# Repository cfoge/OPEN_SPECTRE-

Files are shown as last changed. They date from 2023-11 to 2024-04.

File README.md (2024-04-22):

# OPEN_SPECTRE
## An open-source FPGA-based EMS SPECTRE video synth.
*A project aimed at recreating the EMS SPECTRE VIDEO SYNTHESIZER in HDL*


Open to donations and contributors with FPGA experience. 😀 

###  ✨The EMS SPECTRE Colour Video ✨
>Synthesizer is a unique and revolutionary new product: an instrument capable of producing exciting graphic images on an ordinary television screen. The complete SPECTRE package consists of the synthesizer itself, plus a Sony Trinitron colour monitor, and a Sony black-and-white TV camera. The synthesizer is compact (38"x23.5"x7"), portable (about 35 pounds/15.9KG), and unequalled in its simplicity and versatility.

EMS SPECTRE

### Design Info
#### 🎉Aim 🎉
The aim of this project is to preserve this rare and unique video synth by recreating it in an FPGA, but also to use it as a building block to make a Spectre that is both true to the original and also a modern tool for creativity.
For more info in this process take a look at: 
[Cloning Hardware Ethos](top%20level%20design/Cloning%20a%20process%20not%20a%20device.md)

#### 😎 Tooling 😎
[Parse VHDL](https://github.com/cfoge/VHLD_parse) *Tool set built for this project

#### 🍒Documentation🍒
[Auto Generated Documentation](https://cfoge.github.io/OPEN_SPECTRE-/) **System CURENTLY BROKEN**

#### 🥨Top Level Diagram🥨
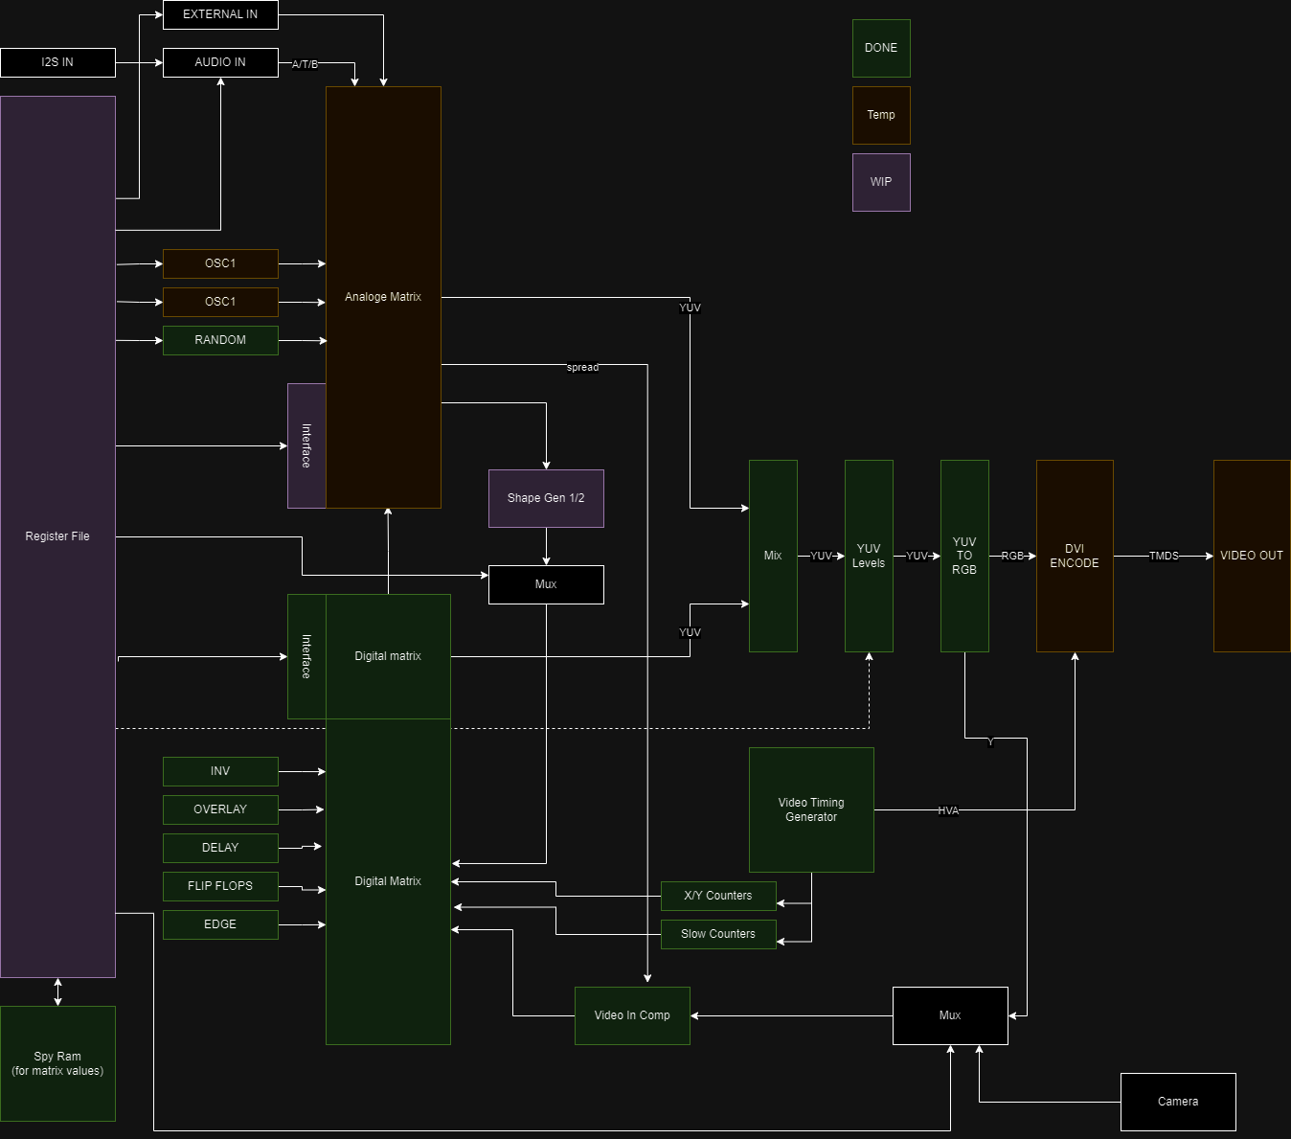
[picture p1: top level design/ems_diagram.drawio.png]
EMS Diagram

Modules

#### 🍨List of Modules and Details Phase 1🍨(WIP)

##### TEST BUILD 1 NOTES:
Simplified elements simulated, need to build a reg file to drive the muxes, there is too much logic for a vio32.
Use microblaze or Zynq to drive a reg file that drives the 20 muxes for Luma 1, Luma2 chroma 1 and chroma 2 (4bit select lines on the Mux)

List of Modules and their current state: (out of date) [here!](modules.md)

### Devlog:


If you want to watch the videos I have been making along the way, you can do that [here!](Devlog.md), or on Youtube, [here!](https://www.youtube.com/watch?v=KFnwisze7SQ&list=PLvfa5uBvhecMLK6bUgnpbkl8QMMuvigXx&pp=gAQBiAQB)

### 🍣Want to Contribute?🍣
Amazing! If you have FPGA and or Verilog/VHDL skills we would love to have you involved. But, first, there are a few things you should know. 
#### What to do first
- Look through the resources folder to get an idea of what the EMS SPECTRE is and how it works
- Look at the top-level diagram and the list of modules
#### Project Details For Contributors
- RTL in VHDL or Verilog (VHDL preferred, no system Verilog 😎 sorry) 
- One module per file with a separate testbench (Verilog or VHDL test benches only, *not everything has one yet, but it should)
- Test benches should print out a message at the end confirming if they are successful or not
- No HSL or auto-generated code, no busses or interfaces for now (will be busses later)
- Use any software you like, but a Vivado project will be supplied
- Follow the template for file headers and comments 📑
- Follow the folder structure for the project 📂
- All code must be open source or MIT license 👍

#### If after all that you still want to be involved you can do one of three things:
- Email us at *OPEN.SPECTRE.PROJECT@gmail.com* and see what modules we need to make at the moment
- Branch the repo, make a module, and submit a pull request 
- If you are not any good at git/GitHub, if you write any modules you can email them to us and we will integrate them into the project

### 🐙License🐙
Creative Commons CC BY-NC

### Contributors
-Remi Freer
-Jacob Stoker
-Robert D Jordan

### Donations
We are very thankful to have received donations from the following people:
Chris Korvin,
Jay Hotchin,
Milton Grimshaw, and more amazing anonymous people. 

[//]: # (These are reference links used in the body of this note and get stripped out when the markdown processor does its job. There is no need to format nicely because it shouldn't be seen. Thanks SO - http://stackoverflow.com/questions/4823468/store-comments-in-markdown-syntax)

   [dill]: <https://github.com/joemccann/dillinger>
   [git-repo-url]: <https://github.com/joemccann/dillinger.git>
   [john gruber]: <http://daringfireball.net>
   [df1]: <http://daringfireball.net/projects/markdown/>
   [markdown-it]: <https://github.com/markdown-it/markdown-it>
   [Ace Editor]: <http://ace.ajax.org>
   [node.js]: <http://nodejs.org>
   [Twitter Bootstrap]: <http://twitter.github.com/bootstrap/>
   [jQuery]: <http://jquery.com>
   [@tjholowaychuk]: <http://twitter.com/tjholowaychuk>
   [express]: <http://expressjs.com>
   [AngularJS]: <http://angularjs.org>
   [Gulp]: <http://gulpjs.com>

   [PlDb]: <https://github.com/joemccann/dillinger/tree/master/plugins/dropbox/README.md>
   [PlGh]: <https://github.com/joemccann/dillinger/tree/master/plugins/github/README.md>
   [PlGd]: <https://github.com/joemccann/dillinger/tree/master/plugins/googledrive/README.md>
   [PlOd]: <https://github.com/joemccann/dillinger/tree/master/plugins/onedrive/README.md>
   [PlMe]: <https://github.com/joemccann/dillinger/tree/master/plugins/medium/README.md>
   [PlGa]: <https://github.com/RahulHP/dillinger/blob/master/plugins/googleanalytics/README.md>

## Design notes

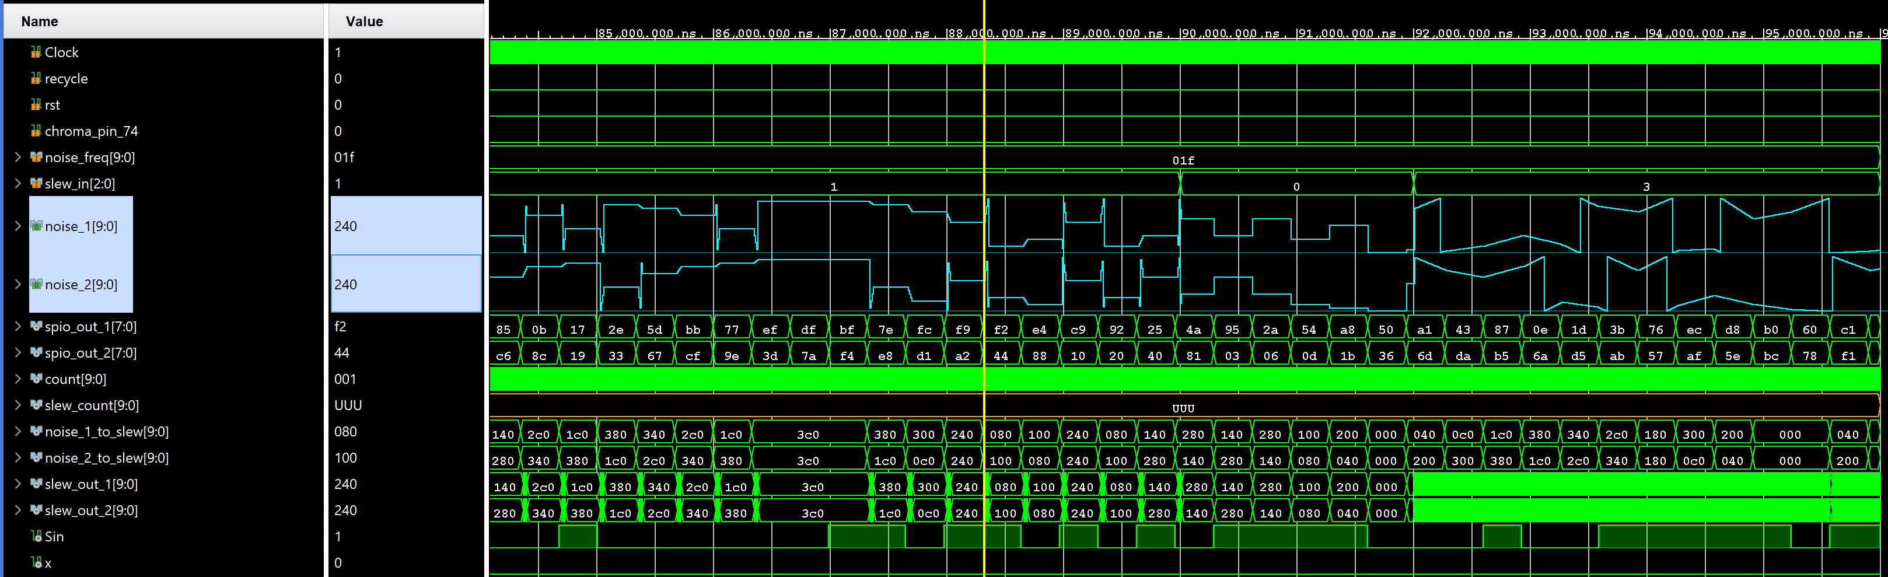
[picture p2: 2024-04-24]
fpga/src/analog_side/random_voltage/docs/random module scope.PNG

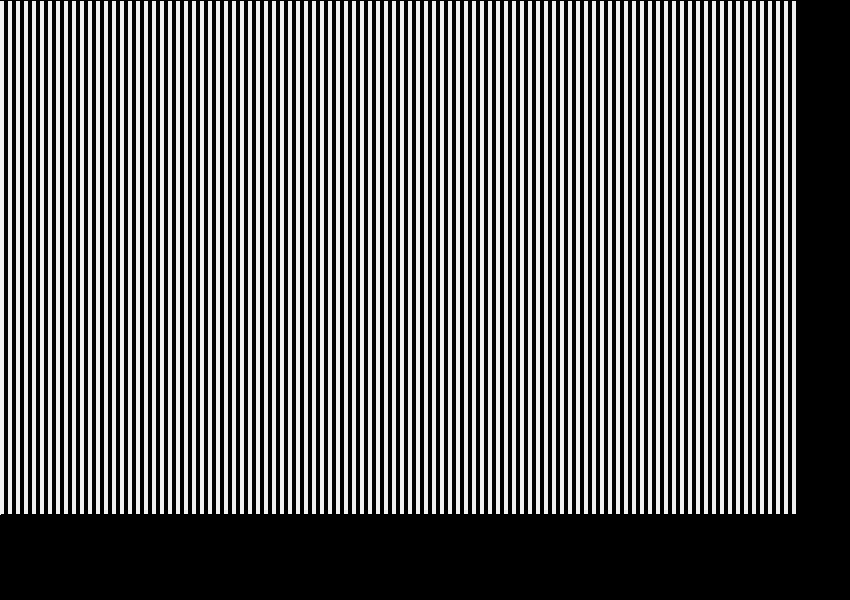
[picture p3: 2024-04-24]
fpga/tools/sim_images/x_cnt_2.png

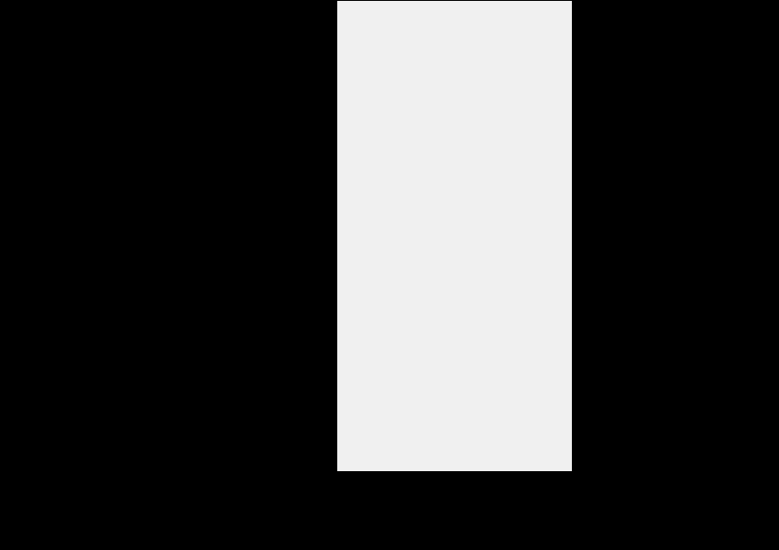
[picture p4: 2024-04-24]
fpga/tools/sim_images/x_cnt_8 blanking on.png

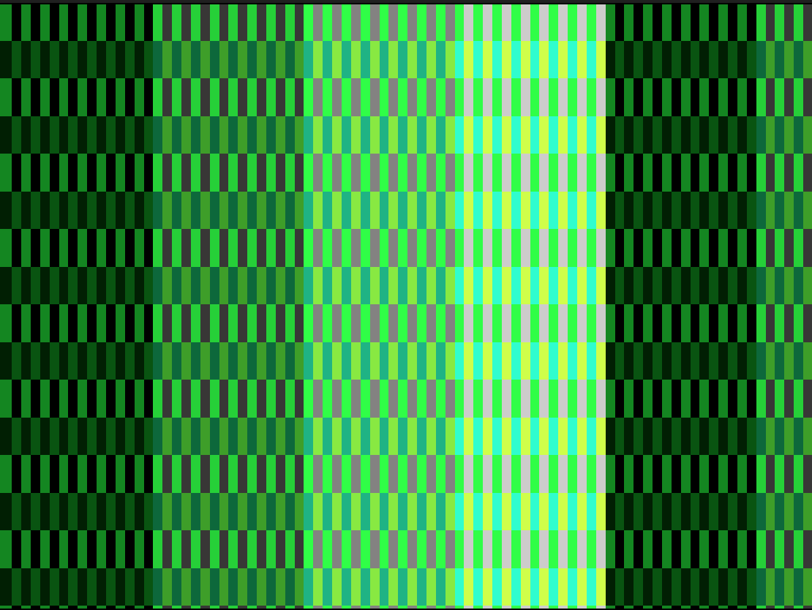
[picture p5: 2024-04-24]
fpga/tools/sim_images/play2.png

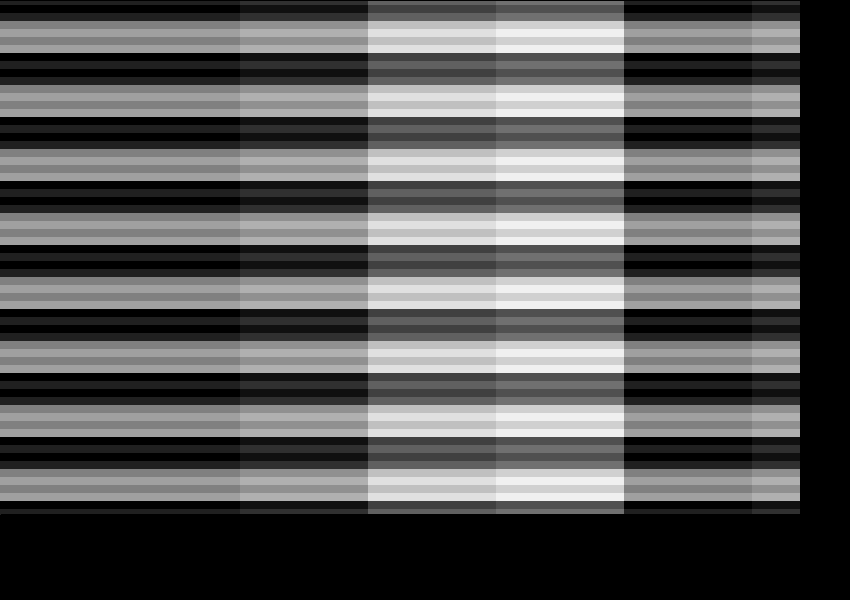
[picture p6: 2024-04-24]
fpga/tools/sim_images/x&y_cnt_combo.png

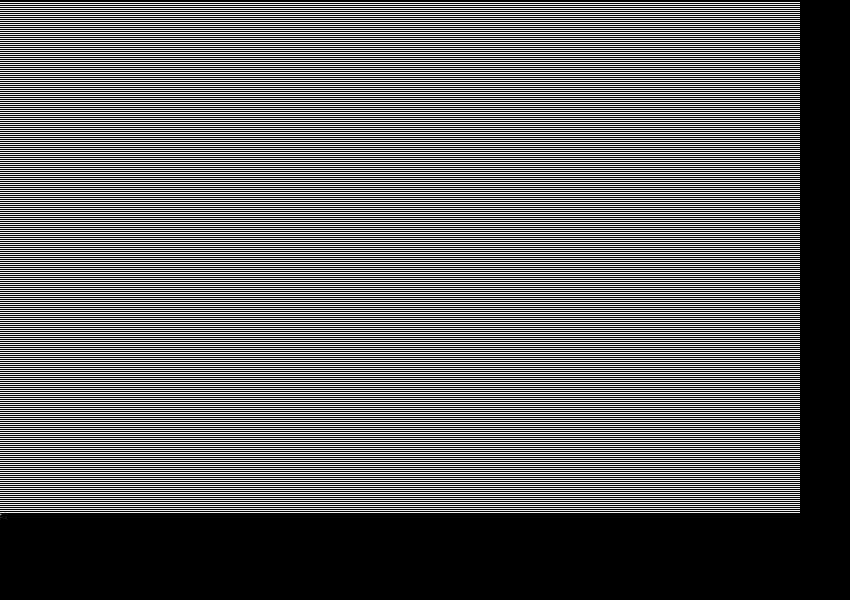
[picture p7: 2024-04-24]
fpga/tools/sim_images/y_cnt_0.png

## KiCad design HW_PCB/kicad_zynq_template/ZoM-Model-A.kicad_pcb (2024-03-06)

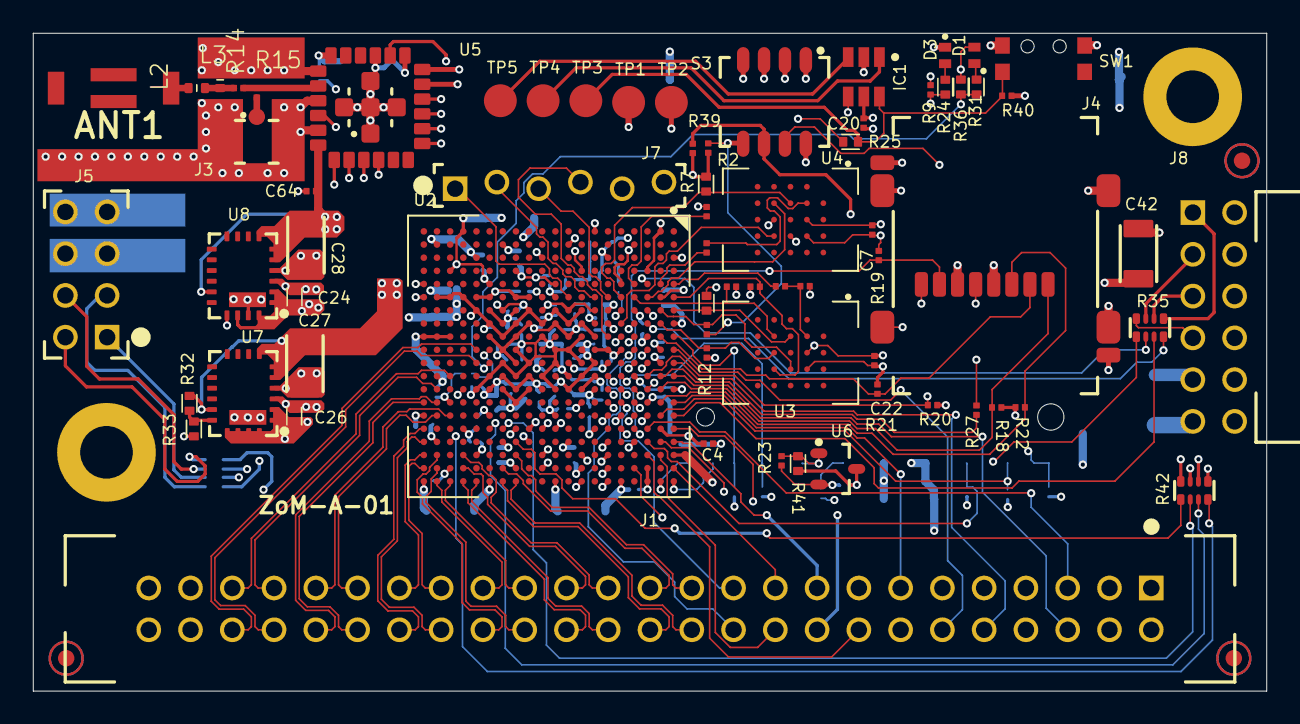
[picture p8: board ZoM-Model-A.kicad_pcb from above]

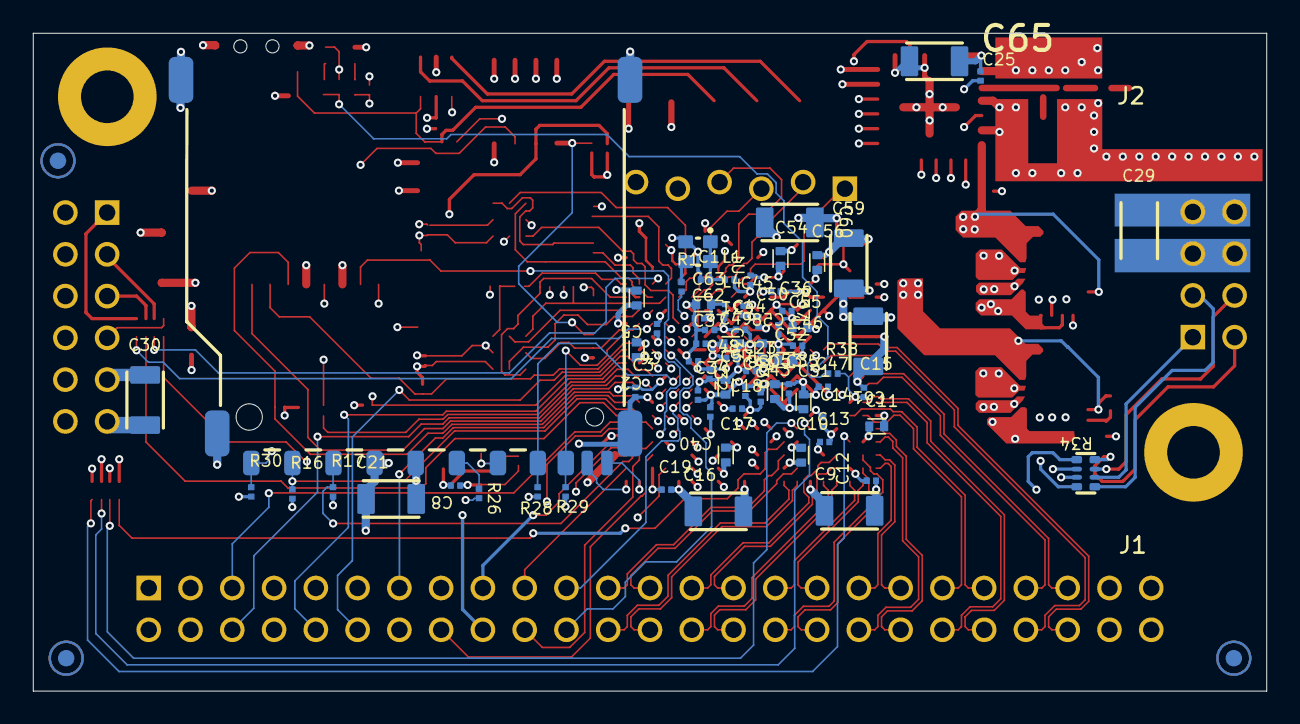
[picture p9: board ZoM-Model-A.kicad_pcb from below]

Board: 6 copper layers, 75.0 x 40.0 mm, 145 parts (72 on the bottom side), 140 nets.

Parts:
ANT1: Antena 2450AT43B100
C1, C8, C23, C34, C35, C36, C37, C41, C43, C44, C45, C46, C47, C48, C50, C64, C65: 470nF; CAPC0603X33N
C2, C5, C10, C11, C17, C24, C26, C63: 4.7µF; _AD_adlib_lib_pcb_TE-IPC7351_CAPC1005X60N.PcbLib_CAPC1005X6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
C3, C4, C6, C7, C12, C13, C14, C15, C18, C19, C20, C22, C31, C32, C33, C38, C39, C40, C62: 470nF; _AD_adlib_lib_pcb_TE-IPC7351_CAPC0603X33N.PcbLib_CAPC0603X3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
C9, C16, C21, C25, C27, C28, C29, C30, C42: 47µF; _AD_adlib_lib_pcb_TE-IPC7351_CAPC3216X180N.PcbLib_CAPC3216X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
C49, C51, C52, C53, C54, C55, C56: 4.7µF; _svn_cad_altium_pcb_contract_tt_tt-svn_ADLIB_dbww_.._lib_pc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
C57, C58: 4.7µF; CAPC1005X60N
C59, C60, C61: 100µF; CAPC3216X180N
D1: LED Red SML-P11UTT86; _AD_adlib_lib_pcb_TE-IPC7351_LEDC1006X25N_RED.PcbLib_LEDC10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
D3: LED Green SML-P11MTT86; _AD_adlib_lib_pcb_TE-IPC7351_LEDC1006X25N_GREEN.PcbLib_LEDC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
H1, H4: Mount.Hole 3.2mm; MHole3_2mm
IC1: Atmel AVR ATtiny10; _tfx_altium_lib_common_pcb_IC_IPC_SOT23-6.PcbLib_SOT23-6
J1: WANNE2,54-50 GERADE; _AD_adlib_lib_pcb_TE_WANNE2,54-50 GERADE.PcbLib_WANNE2,54-5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
J2: MMC SD Socket; _AD_adlib_lib_pcb_TE_104C-TAA0-R.PcbLib_104C-TAA0-R
J3: U.FL-R-SMT-1; _AD_adlib_lib_pcb_TE_U.FL-R-SMT-1.PcbLib_U.FL-R-SMT-1
J4: SCHD3A0100; _AD_adlib_lib_pcb_TE_SCHD3A0100.PcbLib_SCHD3A0100
J5: STIFTLEISTE2.54 OG 2R-8; STIFTLEISTE2_54 OG 2R-8
J7: Stiftleiste versetzt 1-reihig, 6pol.; _AD_adlib_lib_pcb_TE_STIFTLEISTE2_54 OG 1R-6V.PcbLib_STIFTL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
J8: PMod 2x6 Socket 90°; _AD_adlib_lib_pcb_TE_PMod2x6.PcbLib_PMod2x6
L1: BKP0603HS121-T; INDC0603X33N
L2, L3: IND-Ferrite; RESC1005X40R
L4: BKP0603HS121-T; _AD_adlib_lib_pcb_TE-IPC7351_INDC0603X33N.PcbLib_INDC0603X3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
PM1, PM2, PM3, PM4, PM5, PM6: FIDU-DOT - small
R1, R4, R8: 33R; RESC0603X26N
R2, R9, R10: 10K; RESC0603X26N
R3, R7, R24, R31: 470R; RESC1005X40N
R5, R6, R11, R12, R13, R16, R17, R18, R19, R20, R21, R22, R28, R29, R30, R39, R40: 10K; _AD_adlib_lib_pcb_TE-IPC7351_RESC0603X26N.PcbLib_RESC0603X2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
R14, R15: 0; RESC0603X26N
R23, R37: 4K7; _AD_adlib_lib_pcb_TE-IPC7351_RESC0603X26N.PcbLib_RESC0603X2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
R25: 470R; _AD_adlib_lib_pcb_TE-IPC7351_RESC1005X40N.PcbLib_RESC1005X4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
R26, R27: 33R; _AD_adlib_lib_pcb_TE-IPC7351_RESC0603X26N.PcbLib_RESC0603X2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
R32: 200K; _AD_adlib_lib_pcb_TE-IPC7351_RESC1005X40N.PcbLib_RESC1005X4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
R33: 301K; _AD_adlib_lib_pcb_TE-IPC7351_RESC1005X40N.PcbLib_RESC1005X4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
R34, R35, R42: 33R; _AD_adlib_lib_pcb_TE-IPC7351_RESCAX50P100X200X55-8N.PcbLib_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
R36: 680R; RESC1005X40N
R38: 4K7; RESC0603X26N
R41: 0R; _AD_adlib_lib_pcb_TE-IPC7351_RESC1005X40N.PcbLib_RESC1005X4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
S3: CHS-04TA; _AD_adlib_lib_pcb_TE-IPC7351_CHS-04TA.PcbLib_CHS-04TA
SW1: 4pin button; _tfx_altium_lib_common_pcb_BUT-SW_KMS221G_LFS.PcbLib_KMS221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
TP1, TP2, TP3, TP4, TP5: TP; _tfx_altium_lib_common_PCB_TP_TP-SMD-2mm.PcbLib_TP-SMD-2mm
U1: SiT8008AI-73-XXS-33.333333E; 2016
U2: XA7Z020-1CLG400I; _AD_adlib_lib_pcb_TE-IPC7351_BGA400C80P20X20_1700X1700X160N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
U3, U4: W25Q256FVBIG; _AD_adlib_lib_pcb_TE-IPC7351_BGA24C100P5X5_800X600X120N.Pcb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
U5: TiWi-uB2
U6: ATSHA204A-STUCZ-T; _AD_adlib_lib_pcb_TE-IPC7351_SOT95P237X112-3N.PcbLib_SOT95P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
U7, U8: EN5311QI; _AD_adlib_lib_pcb_TE_EN5311QI.PcbLib_EN5311QI

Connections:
1.8V: C16.1, C17.1, C18.1, C19.1, C23.1, C28.1, C32.2, C33.2, C44.1, C46.1, C48.1, C50.1, C52.1, C54.1, C56.1, C58.1, C60.2, C64.1, L4.2, U2.A3, U2.C19, U2.C20, U2.D2, U2.E5, U2.F8, U2.F11, U2.F18, U2.G1, U2.G9, U2.H4, U2.H8, U2.H14, U2.J9, U2.J11, U2.J17, U2.K8, U2.K20, U2.L3, U2.L11, U2.M8, U2.M16, U2.N9, U2.N11, U2.P2, U2.P10, U2.R5, U2.R9, U2.U1, U2.V4, U5.18, U8.5, U8.6, U8.7, U8.15
1V: C27.1, C34.1, C35.1, C36.1, C37.1, C38.1, C39.1, C40.1, C41.1, C43.1, C45.1, C47.1, C49.1, C51.1, C53.1, C55.1, C57.1, C59.1, C61.1, R32.1, U2.G7, U2.G11, U2.G13, U2.H10, U2.H12, U2.J7, U2.J13, U2.K12, U2.L7, U2.L13, U2.M12, U2.N7, U2.N13, U2.P8, U2.P12, U2.R7, U2.R13, U7.5, U7.6, U7.7, U7.15
3.3V: C2.1, C3.1, C4.1, C5.1, C6.1, C7.1, C8.1, C9.1, C10.1, C11.1, C12.1, C13.1, C14.1, C15.1, C20.1, C21.1, C22.2, C24.1, C25.1, C26.1, C29.1, C30.1, C31.2, C42.1, C65.1, D1.A, IC1.5, J1.1, J1.2, J1.49, J1.50, J2.4, J4.4, J5.7, J5.8, J7.6, J8.6, J8.12, L1.1, R2.2, R3.1, R5.2, R7.2, R16.1, R17.1, R18.1, R19.1, R20.1, R21.1, R22.1, R23.2, R28.1, R29.1, R30.1, R36.1, R37.2, R38.2, R39.1, R40.2, TP1.1, U2.A13, U2.B6, U2.B10, U2.B16, U2.D7, U2.D12, U2.E15, U2.K6, U2.M6, U2.N6, U2.N19, U2.R6, U2.R15, U2.T6, U2.T18, U2.U13, U2.V14, U2.W17, U2.Y20, U3.B4, U4.B4, U5.12, U6.2, U7.1, U7.2, U7.17, U7.18, U7.19, U7.20, U8.1, U8.2, U8.18, U8.20
B34_L1_N: J1.46, U2.T10
B34_L1_P: J1.44, U2.T11
B34_L4_N: J1.43, U2.W13
B34_L4_P: J1.45, U2.V12
B34_L7_N: J1.36, U2.Y17
B34_L7_P: J1.38, U2.Y16
B34_L8_N: J1.40, U2.Y14
B34_L8_P: J1.42, U2.W14
B34_L10_N: J1.39, U2.W15
B34_L10_P: J1.41, U2.V15
B34_L12_N: J1.29, U2.U19
B34_L12_P: J1.27, U2.U18
B34_L13_N: J1.25, U2.P19
B34_L13_P: J1.23, U2.N18
B34_L14_N: J1.26, U2.P20
B34_L14_P: J1.24, U2.N20
B34_L15_N: J1.30, U2.U20
B34_L15_P: J1.28, U2.T20
B34_L16_N: J1.33, U2.W20
B34_L16_P: J1.31, U2.V20
B34_L17_N: J1.35, U2.Y19
B34_L17_P: J1.37, U2.Y18
B34_L19_P: R42.3, U2.R16
B34_L21_P: R42.4, U2.V17
B34_L22_N: J1.32, U2.W19
B34_L22_P: J1.34, U2.W18
B34_L23_P: R42.1, U2.N17
B34_L24_N: R42.2, U2.P16
B35_L1_N: J2.11, U2.B20
B35_L2_N: J2.10, U2.A20
B35_L4_P: S3.7, U2.D19
B35_L6_N: U2.F17, U5.22
B35_L8_P: U2.M17, U5.2
B35_L9_P: U2.L19, U5.8
B35_L11_P: U2.L16, U5.3
B35_L14_N: U2.H18, U5.21
B35_L15_N: U2.F20, U5.19
B35_L15_P: U2.F19, U5.20
B35_L17_N: U2.H20, U5.16
B35_L21_N: U2.N16, U5.1
B35_L24_P: U2.K16, U5.4
BOOT_R: R2.1, R6.2, S3.5
BTN: IC1.6, R25.1, R40.1, SW1.2, TP3.1
DONE: R31.2, R36.2, U2.R11
GND: C1.2, C2.2, C3.2, C4.2, C5.2, C6.2, C7.2, C8.2, C9.2, C10.2, C11.2, C12.2, C13.2, C14.2, C15.2, C16.2, C17.2, C18.2, C19.2, C20.2, C21.2, C22.1, C23.2, C24.2, C25.2, C26.2, C27.2, C28.2, C29.2, C30.2, C31.1, C32.1, C33.1, C34.2, C35.2, C36.2, C37.2, C38.2, C39.2, C40.2, C41.2, C42.2, C43.2, C44.2, C45.2, C46.2, C47.2, C48.2, C49.2, C50.2, C51.2, C52.2, C53.2, C54.2, C55.2, C56.2, C57.2, C58.2, C59.2, C60.1, C61.2, C62.2, C63.2, C64.2, C65.2, D3.K, H1.1, H4.1, IC1.2, J1.3, J1.4, J1.47, J1.48, J2.3, J2.12, J3.2, J3.3, J4.6, J4.9, J4.10, J4.F1, J4.F2, J4.F3, J4.F4, J5.5, J5.6, J7.5, J8.5, J8.11, L3.2, R9.1, R10.1, R11.1, R13.1, R33.2, R41.2, S3.1, S3.2, S3.3, S3.4, SW1.3, SW1.4, TP2.1, U1.2, U2.A8, U2.A18, U2.B1, U2.B11, U2.C4, U2.C9, U2.C14, U2.D17, U2.E10, U2.E20, U2.F3, U2.F7, U2.F10, U2.G10, U2.G12, U2.G16, U2.H7, U2.H9, U2.H11, U2.H13, U2.H19, U2.J2, U2.J8, U2.J10, U2.J12, U2.K5, U2.K7, U2.K9, U2.K10, U2.K11, U2.K13, U2.K15, U2.L8, U2.L9, U2.L10, U2.L12, U2.L18, U2.M1, U2.M7, U2.M11, U2.M13, U2.N4, U2.N8, U2.N10, U2.N12, U2.N14, U2.P7, U2.P9, U2.P11, U2.P13, U2.P17, U2.R8, U2.R12, U2.R20, U2.T3, U2.T7, U2.T13, U2.U6, U2.U16, U2.V6, U2.V9, U2.V19, U2.W2, U2.W6, U2.W9, U2.W12, U2.Y5, U2.Y6, U2.Y9, U2.Y15, U3.B3, U4.B3, U5.5, U5.6, U5.7, U5.9, U5.13, U5.15, U5.17, U5.25, U5.26, U5.27, U5.28, U5.29, U6.3, U7.3, U7.4, U7.21, U8.3, U8.4, U8.17, U8.19, U8.21
INIT: R38.1, U2.R10
JTAG_R: R12.1, R39.2, S3.6
MEM_PROTECT: J2.6, R23.1, R41.1, U6.1
MIO7: R9.2, R24.2, U2.D8
MIO14: R35.6, U2.C5
MIO15: R35.8, U2.C8
MIO16: J1.19, U2.A19
MIO17: J1.21, U2.E14
MIO18: J1.20, U2.B18
MIO19: J1.22, U2.D10
MIO20: J1.17, U2.A17
MIO21: J1.18, U2.F14
MIO22: R34.7, U2.B17
MIO23: R34.8, U2.D11
MIO24: R34.5, U2.A16
MIO25: R34.6, U2.F15
MIO26: R35.7, U2.A15
MIO27: R35.5, U2.D13
MIO28: J1.5, U2.C16
MIO29: J1.7, U2.C13
MIO30: J1.9, U2.C15
MIO31: J1.11, U2.E16
MIO32: J1.13, U2.A14
MIO33: J1.15, U2.D15
MIO34: J1.6, U2.A12
MIO35: J1.8, U2.F12
MIO36: J1.10, U2.A11
MIO37: J1.12, U2.A10
MIO38: J1.14, U2.E13
MIO39: J1.16, U2.C18
MIO40: R26.1, U2.D14
MIO41: J2.2, R17.2, U2.C17
MIO42: J2.7, R28.2, U2.E12
MIO43: J2.8, R29.2, U2.A9
MIO44: J2.9, R30.2, U2.F13
MIO45: J2.1, R16.2, U2.B15
MIO46: J4.7, R19.2, U2.D16
MIO47: J4.3, R22.2, U2.B14
MIO48: R27.1, U2.B12
MIO49: J4.8, R20.2, U2.C12
MIO50: J4.1, R18.2, U2.B13
MIO51: J4.2, R21.2, U2.B9
MIO52: S3.8, U2.C10
MIO53: R25.2, U2.C11
NetANT1_1: ANT1.1, L2.2
NetC1_1: C1.1, L1.2, U1.1, U1.4
NetC62_1: C62.1, C63.1, L4.1, U2.G8
NetD1_K: D1.K, R31.1
NetD3_A: D3.A, R24.1
NetIC1_1: IC1.1, TP4.1
NetIC1_3: IC1.3, TP5.1
NetJ2_5: J2.5, R26.2
NetJ3_1: J3.1, R15.1
NetJ4_5: J4.5, R27.2
NetJ5_1: J5.1, R34.2
NetJ5_2: J5.2, R34.4
NetJ5_3: J5.3, R34.1
NetJ5_4: J5.4, R34.3
NetJ8_1: J8.1, R35.1
NetJ8_2: J8.2, R35.3
NetJ8_3: J8.3, R35.2
NetJ8_4: J8.4, R35.4
NetJ8_7: J8.7, R42.8
NetJ8_8: J8.8, R42.7
NetJ8_9: J8.9, R42.6
NetJ8_10: J8.10, R42.5
NetL2_1: L2.1, L3.1, R14.2
NetR1_1: R1.1, U1.3
NetR14_1: R14.1, R15.2, U5.14
NetR32_2: R32.2, R33.1, U7.16
PROG_B: R37.1, U2.L6
PS_CLK: R1.2, U2.E7
PS_POR_B: IC1.4, U2.C7
SPI0_CS: R3.2, U2.A7, U3.C2
SPI0_DQ1/M1: R13.2, U2.D6, U3.D2
SPI0_DQ2/M2: R6.1, U2.B7, U3.C4
SPI0_DQ3/M3: R5.1, U2.A6, U3.D4
SPI0_DQO/M0: R12.2, U2.B8, U3.D3
SPI0_SCK: R4.1, U2.A5
SPI0_SCK/M4: R4.2, R11.2, U3.B2
SPI1_CS: R7.1, U2.E6, U4.C2
SPI1_DQ0: U2.E9, U4.D3
SPI1_DQ1: U2.C6, U4.D2
SPI1_DQ2: U2.D9, U4.C4
SPI1_DQ3: U2.E8, U4.D4
SPI1_SCK: R8.1, U2.B5
SPI1_SCKR: R8.2, U4.B2
SPI_SCK_FB/VCFG1: R10.2, U2.D5
TCK: J7.4, U2.F9
TDI: J7.2, U2.G6
TDO: J7.3, U2.F6
TMS: J7.1, U2.J6

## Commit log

2023-10-17 added basic start code for spi to bram interface
2023-10-18 Add files via upload
    added some basic spi child stuff for decoding incoming spi, needs timeout, needs spi child reset, needs spi write back
2023-10-30 inserted adders for the shape gen values from the regs to get mixed with the mixer outputs
2024-02-15 added template from opensource zynq based fpga model
    [.kicad_sch, B13.kicad_sch, B34.kicad_sch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]
2024-02-15 unfinished fan control module
2024-02-15 pcbs tidied up
    [.kicad_sch, B13.kicad_sch, B34.kicad_sch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]
2024-03-06 making rotery encoders into a system that lets us remap the encoders to any of a bank of registers to avoid the issue of fixed registsters of having to use the CPU to manage the rot encoder values ev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
2024-03-07 started rotary encoder wrapper to handle 5 rotary encoders each with 15 selectable registers
2024-03-11 arty z720 proto type interface started, buttons and rotery encoders added to arty z7 chipkit header
2024-03-24 pcb updated to include 5 rotery encoders,
2024-03-24 button footprints changed to generric 6mm
2024-03-29 buttons added, pots added, layout updated
2024-04-01 prototype pcb finished and checked, jsut neds to be ordered
2024-04-24 directory structure changed to make automated building easier/hopefully make it a bit easier to navigate
    [or_based_matrix_dump.txt, shapes ramp values.ods]
2024-04-24 more directory restructures
    [shapes ramp values.ods]
2024-06-26 Add files via upload
    MicroBlaze processor updated to have 2 bram interfaces and 4 interrupts, also areia minimised, but probably flick that back later if i need it
